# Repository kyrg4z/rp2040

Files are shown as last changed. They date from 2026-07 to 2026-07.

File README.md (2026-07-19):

# RP2040 Devboard with OLED

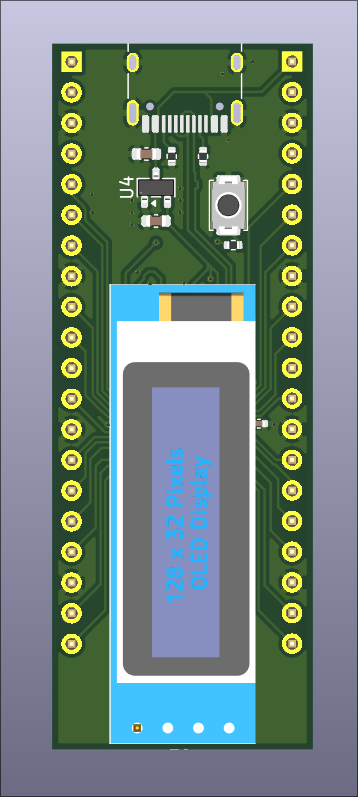
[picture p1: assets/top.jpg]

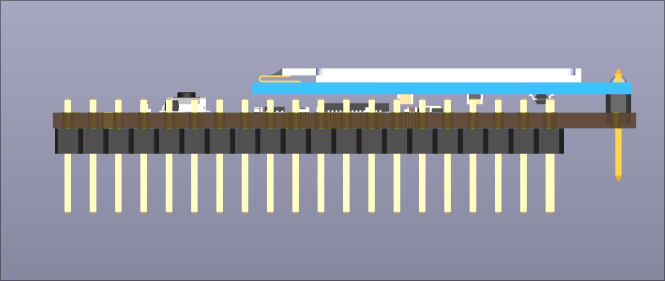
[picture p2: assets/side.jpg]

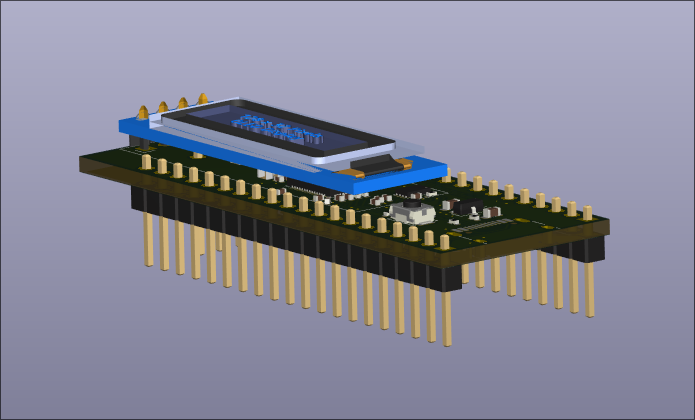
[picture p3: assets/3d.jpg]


## About 

This repository documents my first PCB hardware project. 

The goal was not to create a completely original product but to understand how to develop one. 

I wanted to learn how devboards are designed, study each subsystem and make small modifications. 

Through this project I learned:

- Kicad workflow 
- schematic design
- PCB layouts
- design rules (DRC/ERC) & how to resolve them
- USB connections 
- power distribution 
- decoupling 
- I²C communication
- datasheets 
- adding an OLED display 

## Inspiration

The original inspiration came from Kai Pereira's RP2040 development board and accompanying tutorial.

## What I Changed

- Added an OLED display connected over I²C
- Minor routing/layout changes
- Learned how to resolve DRC issues
- Explored footprint selection and placement

## Current Status

✔ Schematic complete

✔ PCB routed

✔ DRC passes

❌ Board not manufactured yet

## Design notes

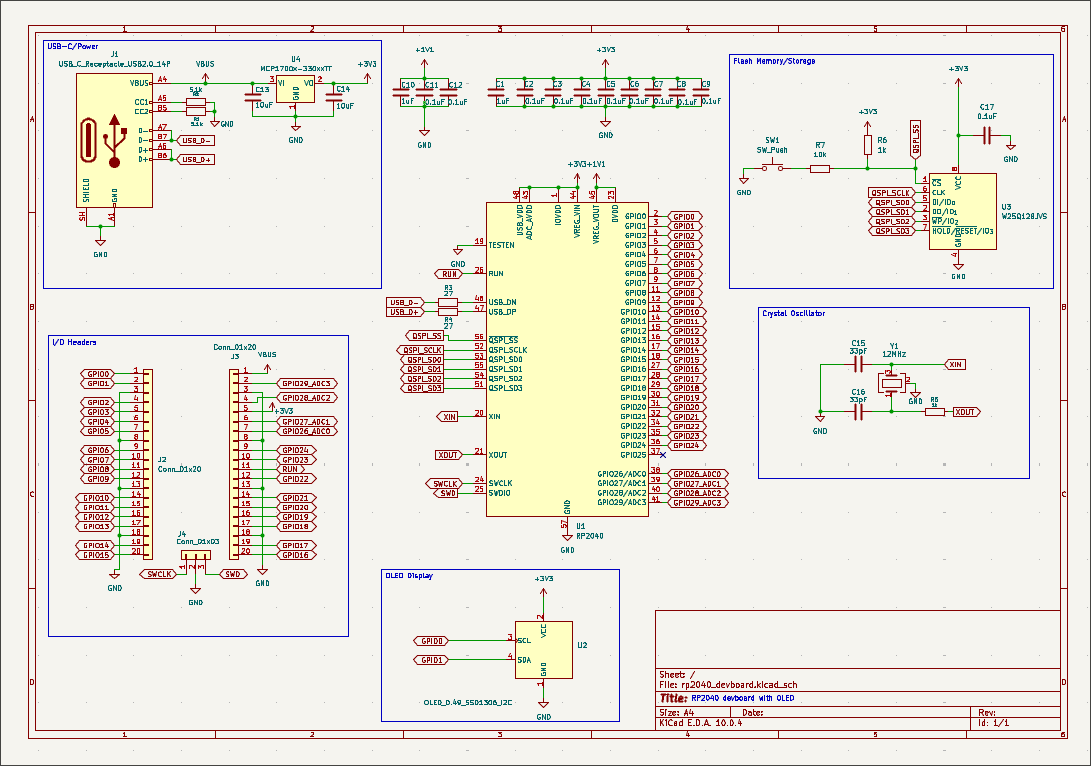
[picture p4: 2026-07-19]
assets/schematic.jpg

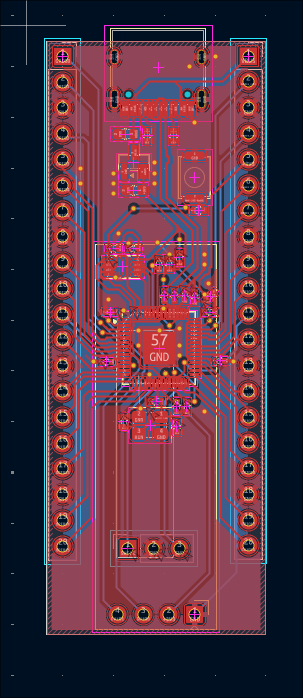
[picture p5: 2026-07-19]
assets/pcb.jpg

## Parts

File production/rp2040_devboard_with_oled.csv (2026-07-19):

Id | Designator | Footprint | Quantity | Designation | Supplier and ref
1 | C1, C10 | C_0402_1005Metric | 2 | 1uF
2 | C2, C3, C4, C5, C6, C7, C8, C9, C11, C12, C17 | C_0402_1005Metric | 11 | 0.1uF
3 | C13, C14 | C_0603_1608Metric | 2 | 10uF
4 | C15, C16 | C_0402_1005Metric | 2 | 33pF
5 | J1 | USB_C_Receptacle_HRO_TYPE-C-31-M-12 | 1 | USB_C_Receptacle_USB2.0_14P
6 | J2, J3 | PinHeader_1x20_P2.54mm_Vertical | 2 | Conn_01x20
7 | J4 | PinHeader_1x03_P2.54mm_Vertical | 1 | Conn_01x03
8 | R1, R2 | R_0402_1005Metric | 2 | 5.1k
9 | R3, R4 | R_0402_1005Metric | 2 | 27
10 | R5, R6 | R_0402_1005Metric | 2 | 1k
11 | R7 | R_0402_1005Metric | 1 | 10k
12 | SW1 | SW_Push_SPST_NO_Alps_SKRK | 1 | SW_Push
13 | U1 | QFN-56-1EP_7x7mm_P0.4mm_EP3.2x3.2mm | 1 | RP2040
14 | U2 | ER_OLEDM0.91_1x-I2C | 1 | OLED_0.49_SSD1306_I2C
15 | U3 | Winbond_USON-8-1EP_3x2mm_P0.5mm_EP0.2x1.6mm | 1 | W25Q128JVS
16 | U4 | SOT-23 | 1 | MCP1700x-330xxTT
17 | Y1 | Crystal_SMD_3225-4Pin_3.2x2.5mm | 1 | 12MHz

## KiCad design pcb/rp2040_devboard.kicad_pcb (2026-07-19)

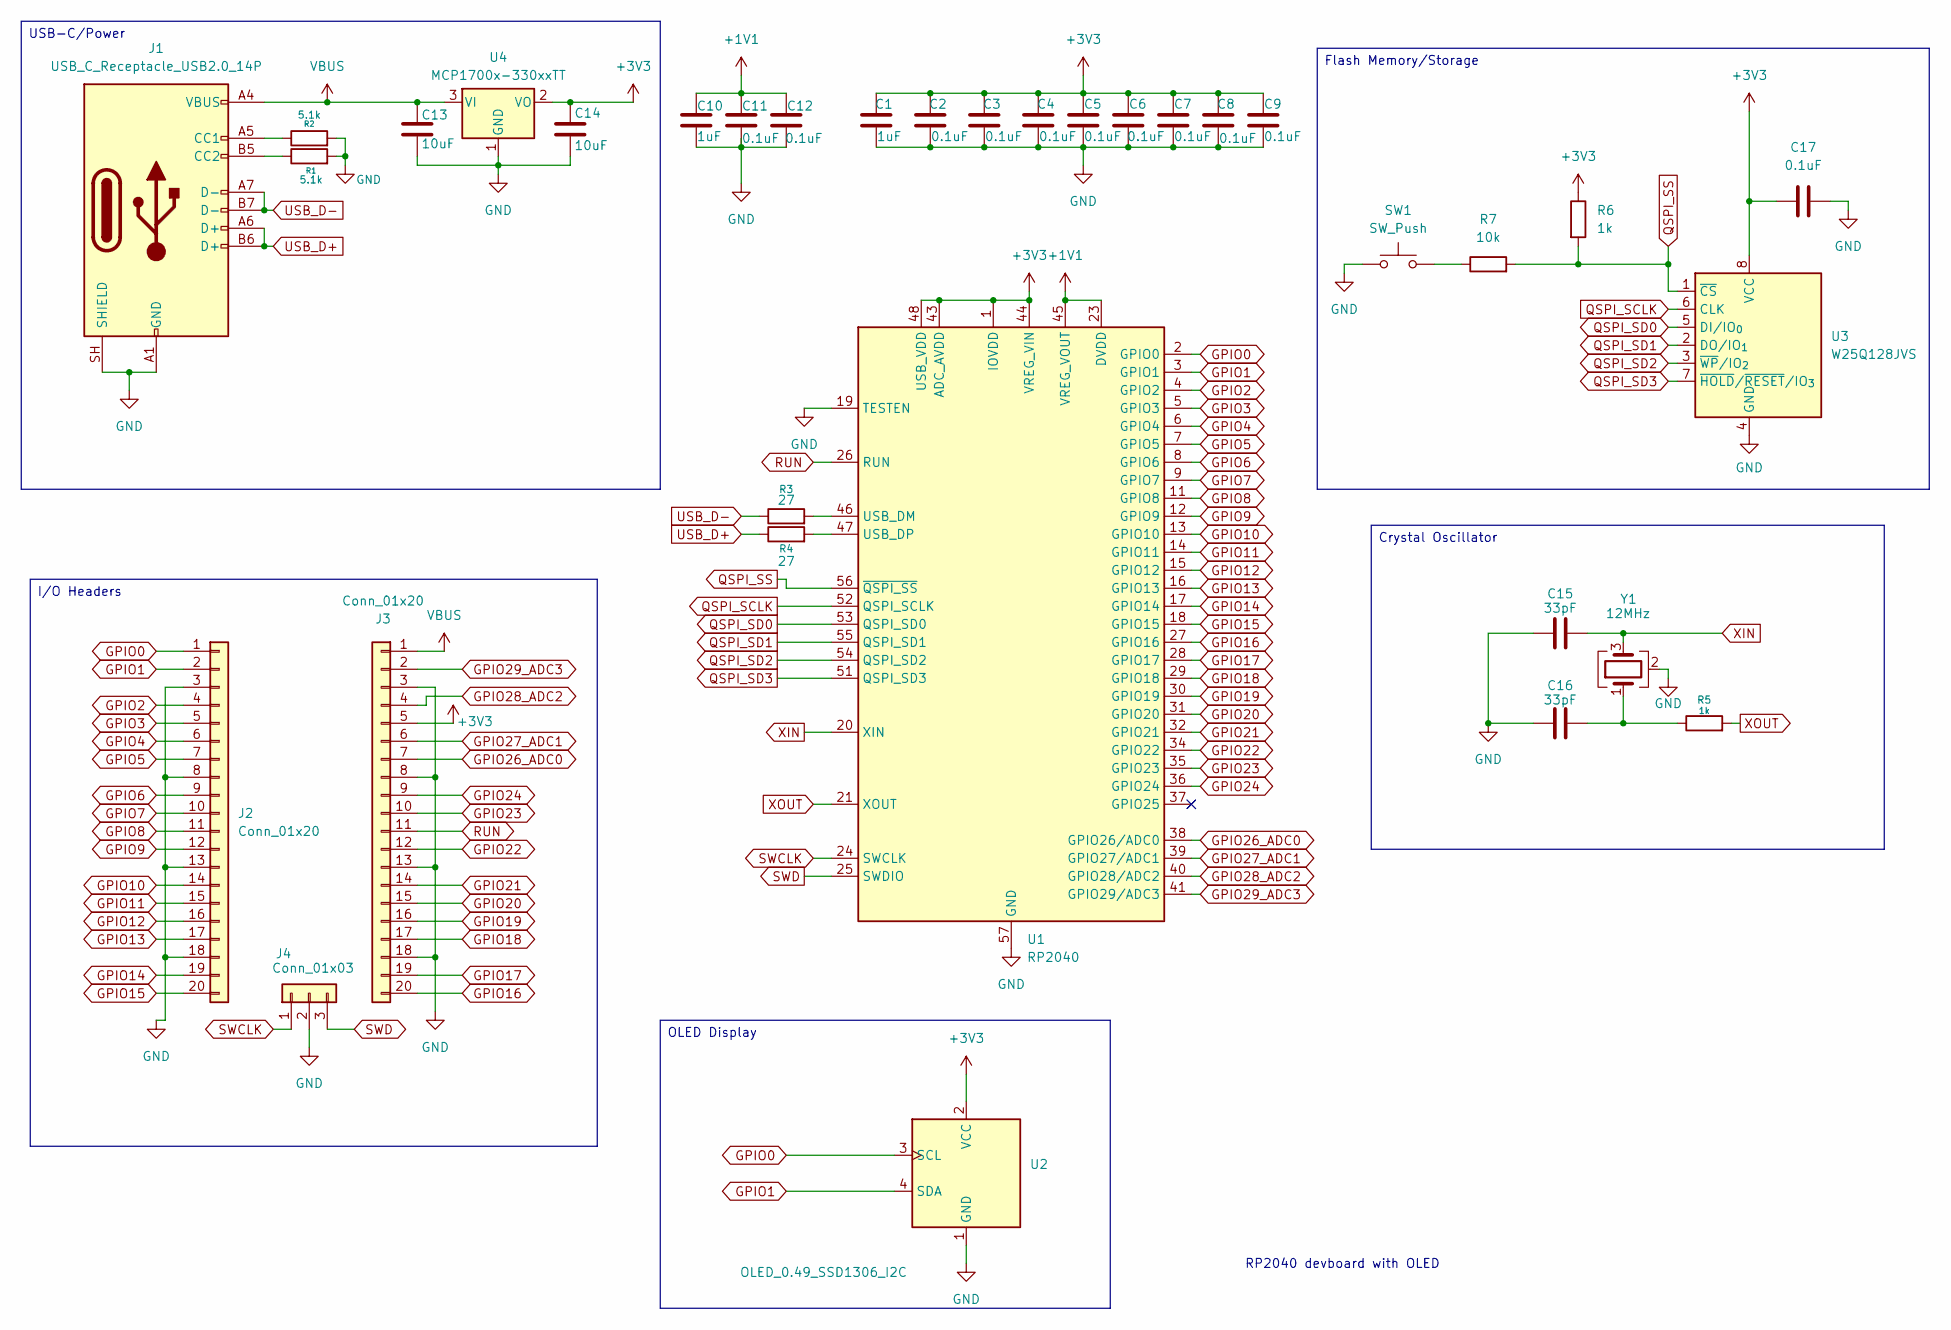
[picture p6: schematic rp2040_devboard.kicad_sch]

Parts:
C1, C10: 1uF; C_0402_1005Metric
C2, C3, C4, C5, C6, C7, C8, C9, C11, C12, C17: 0.1uF; C_0402_1005Metric
C13, C14: 10uF; C_0603_1608Metric
C15, C16: 33pF; C_0402_1005Metric
J1: USB_C_Receptacle_USB2.0_14P; USB_C_Receptacle_HRO_TYPE-C-31-M-12
J2, J3: Conn_01x20; PinHeader_1x20_P2.54mm_Vertical
J4: Conn_01x03; PinHeader_1x03_P2.54mm_Vertical
R1, R2: 5.1k; R_0402_1005Metric
R3, R4: 27; R_0402_1005Metric
R5, R6: 1k; R_0402_1005Metric
R7: 10k; R_0402_1005Metric
SW1: SW_Push; SW_Push_SPST_NO_Alps_SKRK
U1: RP2040; QFN-56-1EP_7x7mm_P0.4mm_EP3.2x3.2mm
U2: OLED_0.49_SSD1306_I2C; ER_OLEDM0.91_1x-I2C
U3: W25Q128JVS; Winbond_USON-8-1EP_3x2mm_P0.5mm_EP0.2x1.6mm
U4: MCP1700x-330xxTT; SOT-23
Y1: 12MHz; Crystal_SMD_3225-4Pin_3.2x2.5mm

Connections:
+1V1: C10.1, C11.1, C12.1, U1.23 (DVDD), U1.45 (VREG_VOUT), U1.50 (DVDD)
+3V3: C1.1, C2.1, C3.1, C4.1, C5.1, C6.1, C7.1, C8.1, C9.1, C14.1, C17.2, J3.5, R6.1, U1.1 (IOVDD), U1.10 (IOVDD), U1.22 (IOVDD), U1.33 (IOVDD), U1.42 (IOVDD), U1.43 (ADC_AVDD), U1.44 (VREG_VIN), U1.48 (USB_VDD), U1.49 (IOVDD), U2.2 (VCC), U3.8 (VCC), U4.2 (VO)
GND: C1.2, C2.2, C3.2, C4.2, C5.2, C6.2, C7.2, C8.2, C9.2, C10.2, C11.2, C12.2, C13.2, C14.2, C15.1, C16.1, C17.1, J1.A1 (GND), J1.A12 (GND), J1.B1 (GND), J1.B12 (GND), J1.SH (SHIELD), J2.3, J2.8, J2.13, J2.18, J3.3, J3.8, J3.13, J3.18, J4.2, R1.2, R2.2, SW1.1, U1.19 (TESTEN), U1.57 (GND), U2.1 (GND), U3.4 (GND), U4.1 (GND), Y1.2 (G), Y1.4 (G)
GPIO0: J2.1, U1.2 (GPIO0), U2.3 (SCL)
GPIO1: J2.2, U1.3 (GPIO1), U2.4 (SDA)
GPIO2: J2.4, U1.4 (GPIO2)
GPIO3: J2.5, U1.5 (GPIO3)
GPIO4: J2.6, U1.6 (GPIO4)
GPIO5: J2.7, U1.7 (GPIO5)
GPIO6: J2.9, U1.8 (GPIO6)
GPIO7: J2.10, U1.9 (GPIO7)
GPIO8: J2.11, U1.11 (GPIO8)
GPIO9: J2.12, U1.12 (GPIO9)
GPIO10: J2.14, U1.13 (GPIO10)
GPIO11: J2.15, U1.14 (GPIO11)
GPIO12: J2.16, U1.15 (GPIO12)
GPIO13: J2.17, U1.16 (GPIO13)
GPIO14: J2.19, U1.17 (GPIO14)
GPIO15: J2.20, U1.18 (GPIO15)
GPIO16: J3.20, U1.27 (GPIO16)
GPIO17: J3.19, U1.28 (GPIO17)
GPIO18: J3.17, U1.29 (GPIO18)
GPIO19: J3.16, U1.30 (GPIO19)
GPIO20: J3.15, U1.31 (GPIO20)
GPIO21: J3.14, U1.32 (GPIO21)
GPIO22: J3.12, U1.34 (GPIO22)
GPIO23: J3.10, U1.35 (GPIO23)
GPIO24: J3.9, U1.36 (GPIO24)
GPIO26_ADC0: J3.7, U1.38 (GPIO26/ADC0)
GPIO27_ADC1: J3.6, U1.39 (GPIO27/ADC1)
GPIO28_ADC2: J3.4, U1.40 (GPIO28/ADC2)
GPIO29_ADC3: J3.2, U1.41 (GPIO29/ADC3)
unnamed: C16.2, R5.1, Y1.1
unnamed: J1.A5 (CC1), R2.1
unnamed: J1.B5 (CC2), R1.1
unnamed: R7.1, SW1.2
unnamed: R3.2, U1.46 (USB_DM)
unnamed: R4.2, U1.47 (USB_DP)
QSPI_SCLK: U1.52 (QSPI_SCLK), U3.6 (CLK)
QSPI_SD0: U1.53 (QSPI_SD0), U3.5 (DI/IO_{0})
QSPI_SD1: U1.55 (QSPI_SD1), U3.2 (DO/IO_{1})
QSPI_SD2: U1.54 (QSPI_SD2), U3.3 (~WP/IO_{2})
QSPI_SD3: U1.51 (QSPI_SD3), U3.7 (~HOLD/~RESET/IO_{3})
QSPI_SS: R6.2, R7.2, U1.56 (~QSPI_SS), U3.1 (~CS)
RUN: J3.11, U1.26 (RUN)
SWCLK: J4.1, U1.24 (SWCLK)
SWD: J4.3, U1.25 (SWDIO)
USB_D+: J1.A6 (D+), J1.B6 (D+), R4.1
USB_D-: J1.A7 (D-), J1.B7 (D-), R3.1
VBUS: C13.1, J1.A4 (VBUS), J1.A9 (VBUS), J1.B4 (VBUS), J1.B9 (VBUS), J3.1, U4.3 (VI)
XIN: C15.2, U1.20 (XIN), Y1.3
XOUT: R5.2, U1.21 (XOUT)

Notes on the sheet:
RP2040 devboard with OLED
I/O Headers
Crystal Oscillator
Flash Memory/Storage
USB-C/Power
OLED Display

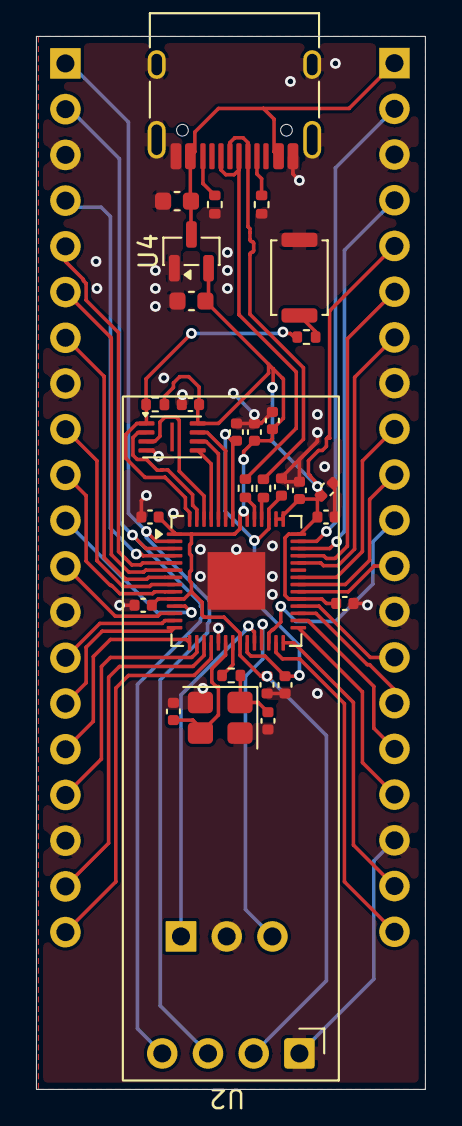
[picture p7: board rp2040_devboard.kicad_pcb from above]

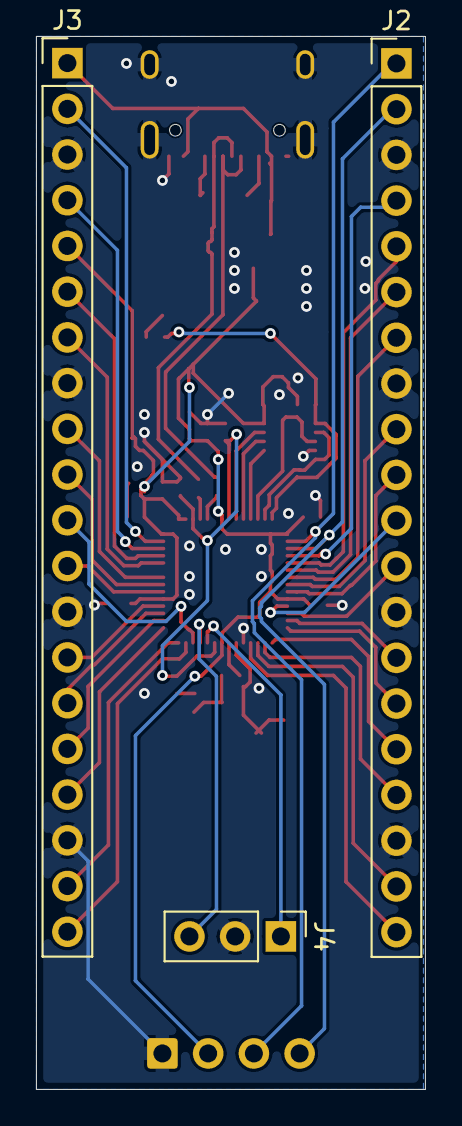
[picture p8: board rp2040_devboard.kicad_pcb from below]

Board: 2 copper layers, 21.6 x 58.5 mm, 34 parts (3 on the bottom side), 52 nets.

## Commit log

2026-05-05 first commit, starting the schematic
    [rp2040_devboard.kicad_pcb, rp2040_devboard.kicad_sch]
2026-05-06 USB-C created and added couple of global labels
    [rp2040_devboard.kicad_sch]
2026-05-07 Added crystal oscilator to the schematic
    [rp2040_devboard.kicad_sch]
2026-07-01 almost finished the schematic
    [rp2040_devboard.kicad_sch]
2026-07-04 finished the schematic, added footprints
    [rp2040_devboard.kicad_sch]
2026-07-05 starting the routing process
    [rp2040_devboard.kicad_pcb, rp2040_devboard.kicad_sch]
2026-07-06 continuing routing, figuring out journaling
    [rp2040_devboard.kicad_pcb, rp2040_devboard.kicad_sch]
2026-07-10 finished routing, fixed drc errors
    [rp2040_devboard.kicad_pcb]
2026-07-19 added readme, working on journals
    [rp2040_devboard.kicad_pcb, rp2040_devboard.kicad_sch, rp2040_devboard_with_oled.csv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]
